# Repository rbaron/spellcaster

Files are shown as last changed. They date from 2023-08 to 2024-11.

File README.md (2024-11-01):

spellcaster Demo (https://youtu.be/c5Yf7bW8n6s)

spellcaster is a home automation magic wand. Click on the thumbnail above to watch it in action.

# How does it work?
An accelerometer and gyroscope are used to capture gestures ("spells"). Cast spells are then compared against previously stored ones. An action is triggered if there's a good match.

Different actions can be triggered. For example:
- A [BTHome.io](https://bthome.io) Bluetooth Low Energy (BLE) packet can be emitted and handled in [Home Assistant](https://www.home-assistant.io/).
- A Zigbee Cluster action, similarly handled in Home Assistant automations
- A [BLE-HID](https://novelbits.io/bluetooth-hid-devices-an-intro/) to simulate a key press on a computer, macro pad-style

In the "Software" section below, there are some firmware samples for each of these actions and more.

[This blog post](https://rbaron.net/blog/2023/10/27/spellcaster-a-home-automation-magic-wand.html) has a deeper dive into how everything works.

# Project status
It sort of works, but there are caveats. Reliability and usability need improvement -- it's easy to [hold it wrong](https://www.wired.com/2010/06/iphone-4-holding-it-wrong/). See "User interface" below. The code also needs the proverbial cleaning up.

Approach this project as a fun experiment. Expect fun and experimental support.

# Hardware
PCB

* [nRF52833](https://www.nordicsemi.com/Products/nRF52833) MCU
* [LSM6DSL](https://www.st.com/en/mems-and-sensors/lsm6dsl.html) IMU
* [Mini vibration motor](https://www.aliexpress.com/item/1005004653448729.html) for tactile feedback
* Powered by 2xAAA batteries

The [`kicad/`](./kicad/) directory contains the design and fabrication files. I used [JLCPCB](https://jlcpcb.com/) for manufacturing and assembly.

# User interface
## Casting spells
There is no on/off switch by design. To signal the *start of spell*, hold the wand horizontally flat. Once you start moving it, the gesture will start to be collected. To signal the *end of spell*, hold the wand horizontally flat again. Spells need to be between 500 milliseconds and 3 seconds in length.

## Record mode
To store a new spell in slot `S`, press the `A` button `S` times and cast a spell as described above. If everything goes well, the LED will flash five times and you will be switched to replay mode.

In this video you can see five different spells being recorded:

spellcaster recording spells (https://youtu.be/6D_qe5v8ILQ)

## Replay mode
This is the default mode in which spellcaster will live most of its life. Once a spell is cast, it will be compared to previously stored spells. If a good match is found, a vibration pattern is executed and an action will be triggered.

### On false positives
The matching algorithm is optimized for _something to happen_. There is a low threshold for matching spells, and often two or more will be sufficiently matched. This depends on how similar spells are, but the best matching spell will always be selected. The idea is that, when we intentionally cast a spell, the correct one will almost always be selected, instead of -- sometimes -- none. On the other hand, previously unseen spells may trigger a false positive.

This is done to mainly prevent the sorry sight of a full grown adult waving a wand in the air in front of friends and family at a dinner party and nothing happening. Don't ask. A better solution is to further tune the spell matching algorithm to be more robust against these cases, while retaining the precision when the casting is intentional. Another idea is to add an invisible capacitive touch sensor to the handle, which would also allow for much deeper sleep modes. Something to be improved.

## Deep sleep mode
If spellcaster is still for 10 seconds, it will enter the lowest power mode at around 65 uA. Most of which goes to the accelerometer, which lies semi-awake in a low power state waiting for movement. This can mostly likely be optimized further. Any movement will wake it up and into replay mode.

# Software
There are a few sample firmwares in the repository. They are all written with Nordic's [nRF Connect SDK](https://www.nordicsemi.com/Products/Development-software/nRF-Connect-SDK). Most samples are adapted from the SDK's examples.

| Directory | Description |
| --- | --- |
|[`code/sclib`](./code/sclib/)| Generic spellcaster library. Handles spell casting, storing and signal processing. Used by all other samples.|
|[`code/samples/ble-bthome`](./code/samples/ble-bthome/)|Matched spell `S` trigger a [BTHome.io](https://bthome.io) action that is equivalent to `S` button presses. This can then be used by [Home Assistant](https://homeassistant.io) automations. |
|[`code/samples/ble-hid`](./code/samples/ble-hid/)|spellcaster pairs with your computer via BLE. Matched spell `S` trigger a BLE-HID action that simulates a key press following the configurable [keymap](https://github.com/rbaron/spellcaster/blob/fc7ee0511366e4b62a08713fc59aa67fac9f286a/code/samples/ble-hid/src/main.c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).|
|[`code/samples/zigbee`](./code/samples/zigbee/)|Matched spells trigger Zigbee Cluster actions that can be used by [Home Assistant](https://homeassistant.io) automations. Unfortunately, the Zigbee specs don't define magic wand clusters, so the [spellcaster.py ZHA Quirk](https://github.com/rbaron/spellcaster/blob/main/code/samples/zigbee/zha/quirks/spellcaster.py) needs to be installed. With it, matched spell on slot `S` appears to be a "dim light" command with step `S`. Yikes! (And it's not even the worst hack around here). |
|[`code/samples/ble-dump`](./code/samples/ble-dump/)|Dumps raw accel & gyro spells over BLE. The [client.py](https://github.com/rbaron/spellcaster/blob/main/code/samples/ble-dump/client/client.py) connects to spellcaster and dumps the data to a file. This is how I collected the data for tuning the spell matching without cables getting in the way.|

## Building the samples
These are standard nRF Connect SDK projects with Zephyr RTOS, and the [official docs](https://nrfconnect.github.io/vscode-nrf-connect/index.html) apply. The [b-parasite project](https://github.com/rbaron/b-parasite) uses a similar setup with a generic library and different samples, and [the Wiki](https://github.com/rbaron/b-parasite/wiki/How-to-Build-the-Firmware-Samples) contains more details and alternatives.

## Flashing the samples
The samples are flashed with ARM's usual [SWD](https://developer.arm.com/documentation/ihi0031/a/The-Serial-Wire-Debug-Port--SW-DP-/Introduction-to-the-ARM-Serial-Wire-Debug--SWD--protocol). The [official docs](https://nrfconnect.github.io/vscode-nrf-connect/get_started/quick_debug.html) also apply. The only caveat is the custom, slim 6-testpoint SWD pins on the PCB. It also happens to the the exact same as described in the [b-parasite Wiki](https://github.com/rbaron/b-parasite/wiki/How-to-Flash-the-Firmware-Samples).

# Data analysis
The [`data/`](./data/) directory contains a bunch of Jupyter notebooks I used to tune the spell matching and some of the raw collected data.

# 3D printed case
fusion-case

The [`3dprint/`](./3dprint/) directory contains the STEP files for a 3D printed case. It's okay-ish, but could use some love. The 3D printed springs lose some tension after a while, and so do the clamps that hold both halves together. On the bright side, there's no glue nor screws involved. You can watch a video of the full assembly process [here](https://www.youtube.com/watch?v=kVlnX7w-8rc).

# License
## Hardware
spellcaster hardware © 2023 by rbaron is licensed under Creative Commons Attribution-ShareAlike 4.0 International (CC BY-SA 4.0). See [deed](https://creativecommons.org/licenses/by-sa/4.0/).

## Software
Software in this repository is licensed under the [MIT license](https://opensource.org/licenses/MIT). See [LICENSE_SOFTWARE](./LICENSE_SOFTWARE).

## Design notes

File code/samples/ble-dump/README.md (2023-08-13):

# check
A sample for checking the spellcaster board.

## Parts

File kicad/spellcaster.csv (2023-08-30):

Comment | Designator | Footprint | LCSC
4.7u | C1 | Capacitor_SMD:C_0402_1005Metric | C368809
100p | C11 | Capacitor_SMD:C_0402_1005Metric | C1546
47n | C13 | Capacitor_SMD:C_0402_1005Metric | C237221
12p | C2,C3,C4,C6 | Capacitor_SMD:C_0402_1005Metric | C1547
100n | C5,C10,C12,C14,C16 | Capacitor_SMD:C_0402_1005Metric | C1525
1p | C7 | Capacitor_SMD:C_0402_1005Metric | C1550
1.2p | C8 | Capacitor_SMD:C_0402_1005Metric | C1551
1u | C9,C15 | Capacitor_SMD:C_0402_1005Metric | C52923
LED | D1 | LED_SMD:LED_0603_1608Metric | C2286
1N4148W | D2 | Diode_SMD:D_SOD-323 | C2128
4.7nH | L1 | Inductor_SMD:L_0402_1005Metric | C963987
2.2nH | L2 | Inductor_SMD:L_0402_1005Metric | C108254
15nH | L3 | Inductor_SMD:L_0402_1005Metric | C27143
10uH | L4 | Inductor_SMD:L_1206_3216Metric | C1051
2N7002 | Q1 | Package_TO_SOT_SMD:SOT-23 | C8545
1k | R1 | Resistor_SMD:R_0402_1005Metric | C11702
10k | R2,R3,R4 | Resistor_SMD:R_0402_1005Metric | C60490
B3U-1000P | S1,S2 | Snapeda:SW_B3U-1000P | C231329
nRF52820-QDxx | U1 | Package_DFN_QFN:QFN-40-1EP_5x5mm_P0.4mm_EP3.6x3.6mm | C2895249
LSM6DSL | U2 | Package_LGA:LGA-14_3x2.5mm_P0.5mm_LayoutBorder3x4y | C126672
32k | Y1 | Crystal:Crystal_SMD_3215-2Pin_3.2x1.5mm | C32346
Crystal_GND24 | Y2 | Crystal:Crystal_SMD_2016-4Pin_2.0x1.6mm | C2149195

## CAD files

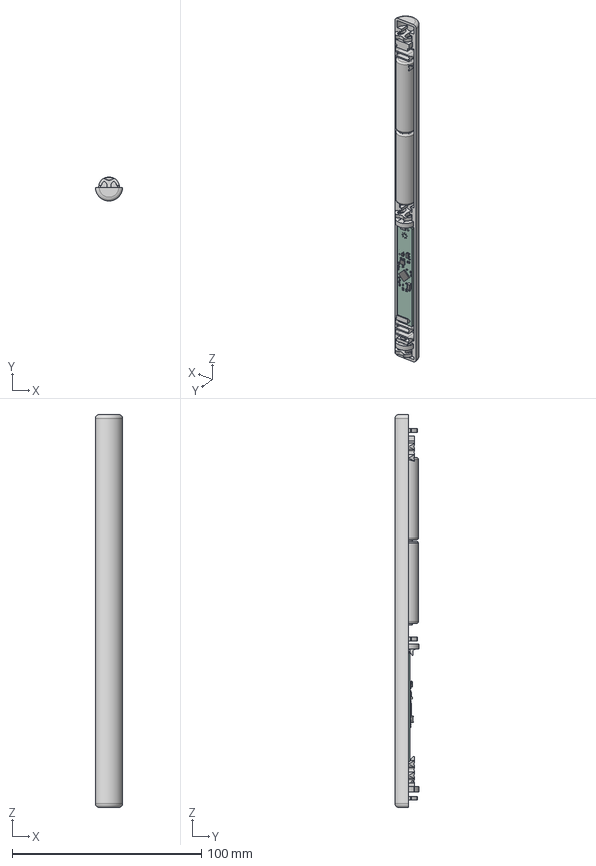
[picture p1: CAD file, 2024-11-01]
3dprint/spellcaster case.step
14.4 x 12.7 x 207.4 mm
PCB
batt1 x 2
vibration_motor
case
clip
spring
pcb_support

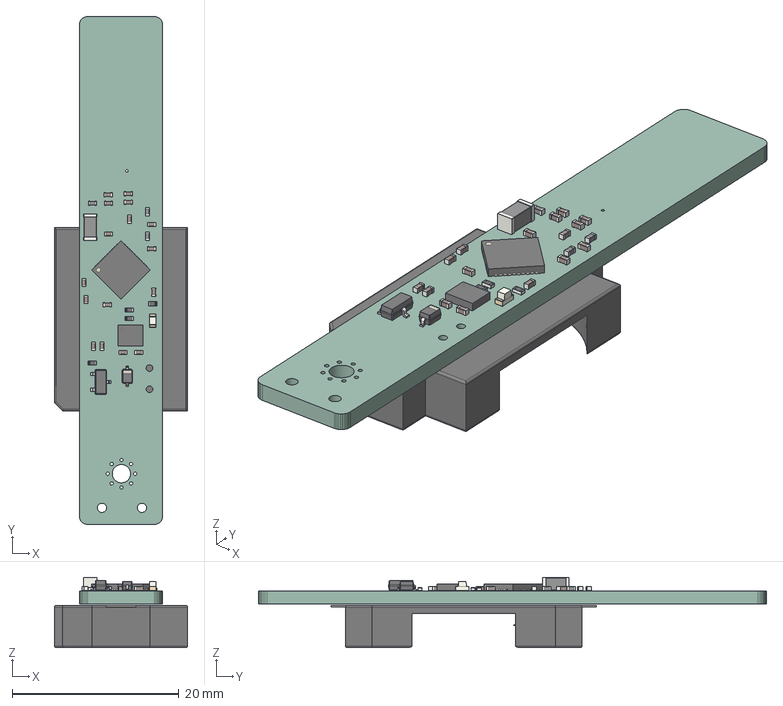
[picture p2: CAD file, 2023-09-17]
3dprint/spellcaster-pcb.step
16.0 x 61.0 x 8.46 mm
PCB

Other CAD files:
3dprint/spellcaster case.f3d

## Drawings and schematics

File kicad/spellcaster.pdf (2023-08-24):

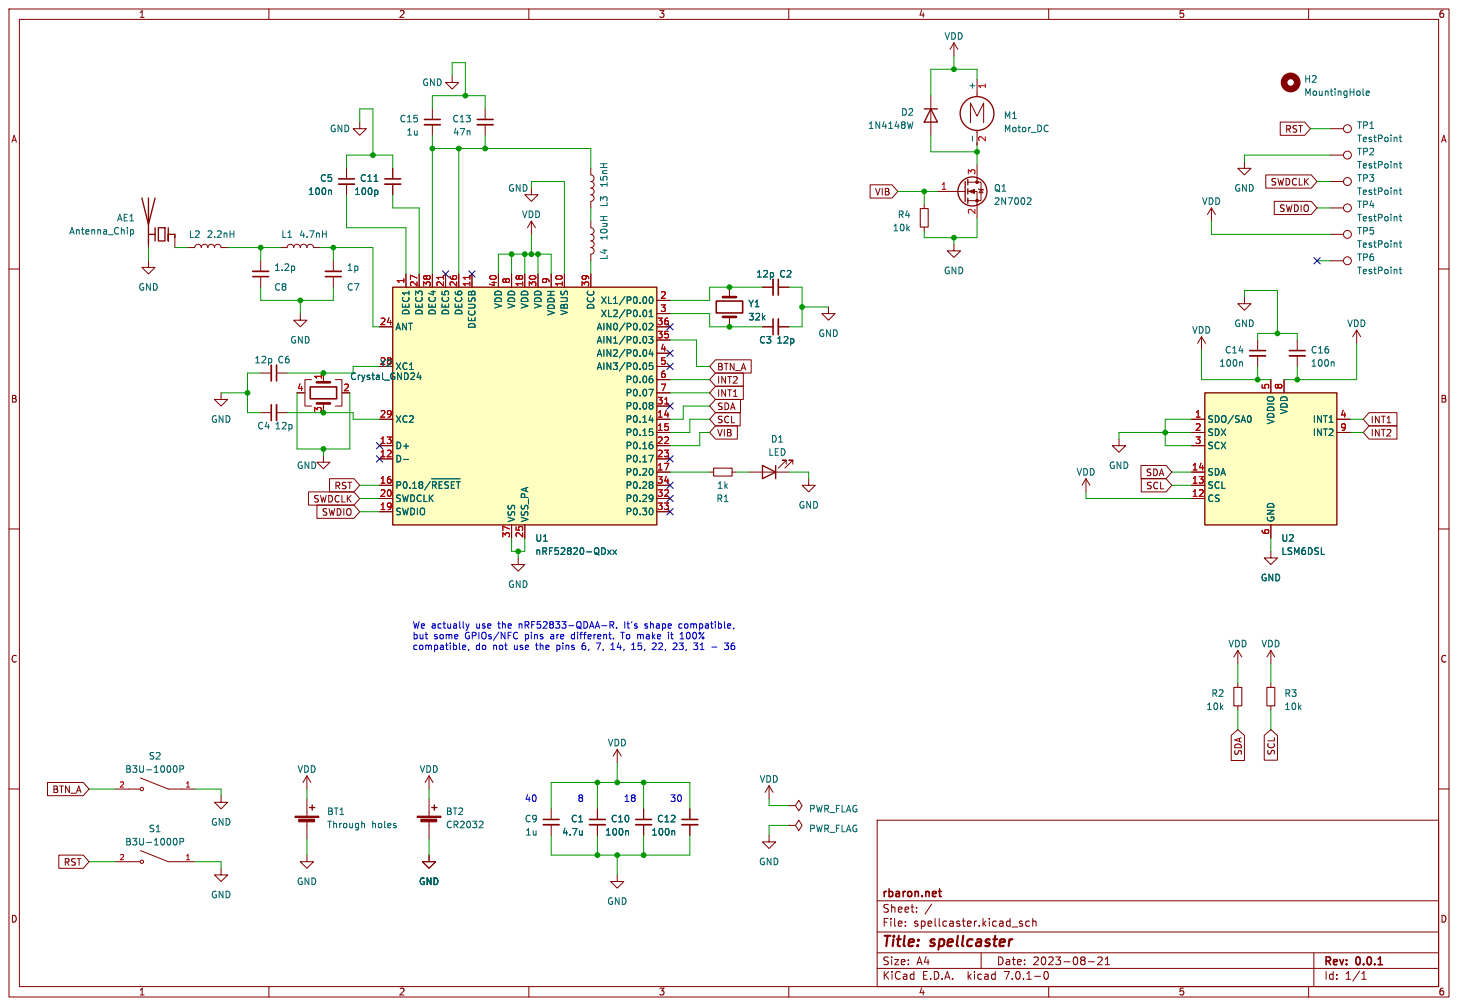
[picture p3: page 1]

1 VBUS 10 DECUSB 11 D- 12 D+ 13 P0.14 14 P0.15 15 P0.18/~{RESET} 16 P0.20 17 VDD 18 SWDIO 19 XL1/P0.00 2 SWDCLK 20 DEC5 21 P0.16 22 P0.17 23 ANT 24 VSS_PA 25 DEC6 26 DEC3 27 XC1 28 XC2 29 XL2/P0.01 VDD 3 30 P0.08 31 P0.29 32 P0.30 33 P0.28 34 AIN1/P0.03 35 AIN0/P0.02 36 VSS 37 DEC4 38 DCC 39 AIN2/P0.04 4 VDD 40 AIN3/P0.05 5 P0.06 6 P0.07 7 VDD

nRF52820-QDxx DEC1

Id: 1/1 Title: spellcaster File: spellcaster.kicad_sch Sheet: / rbaron.net VDD GND

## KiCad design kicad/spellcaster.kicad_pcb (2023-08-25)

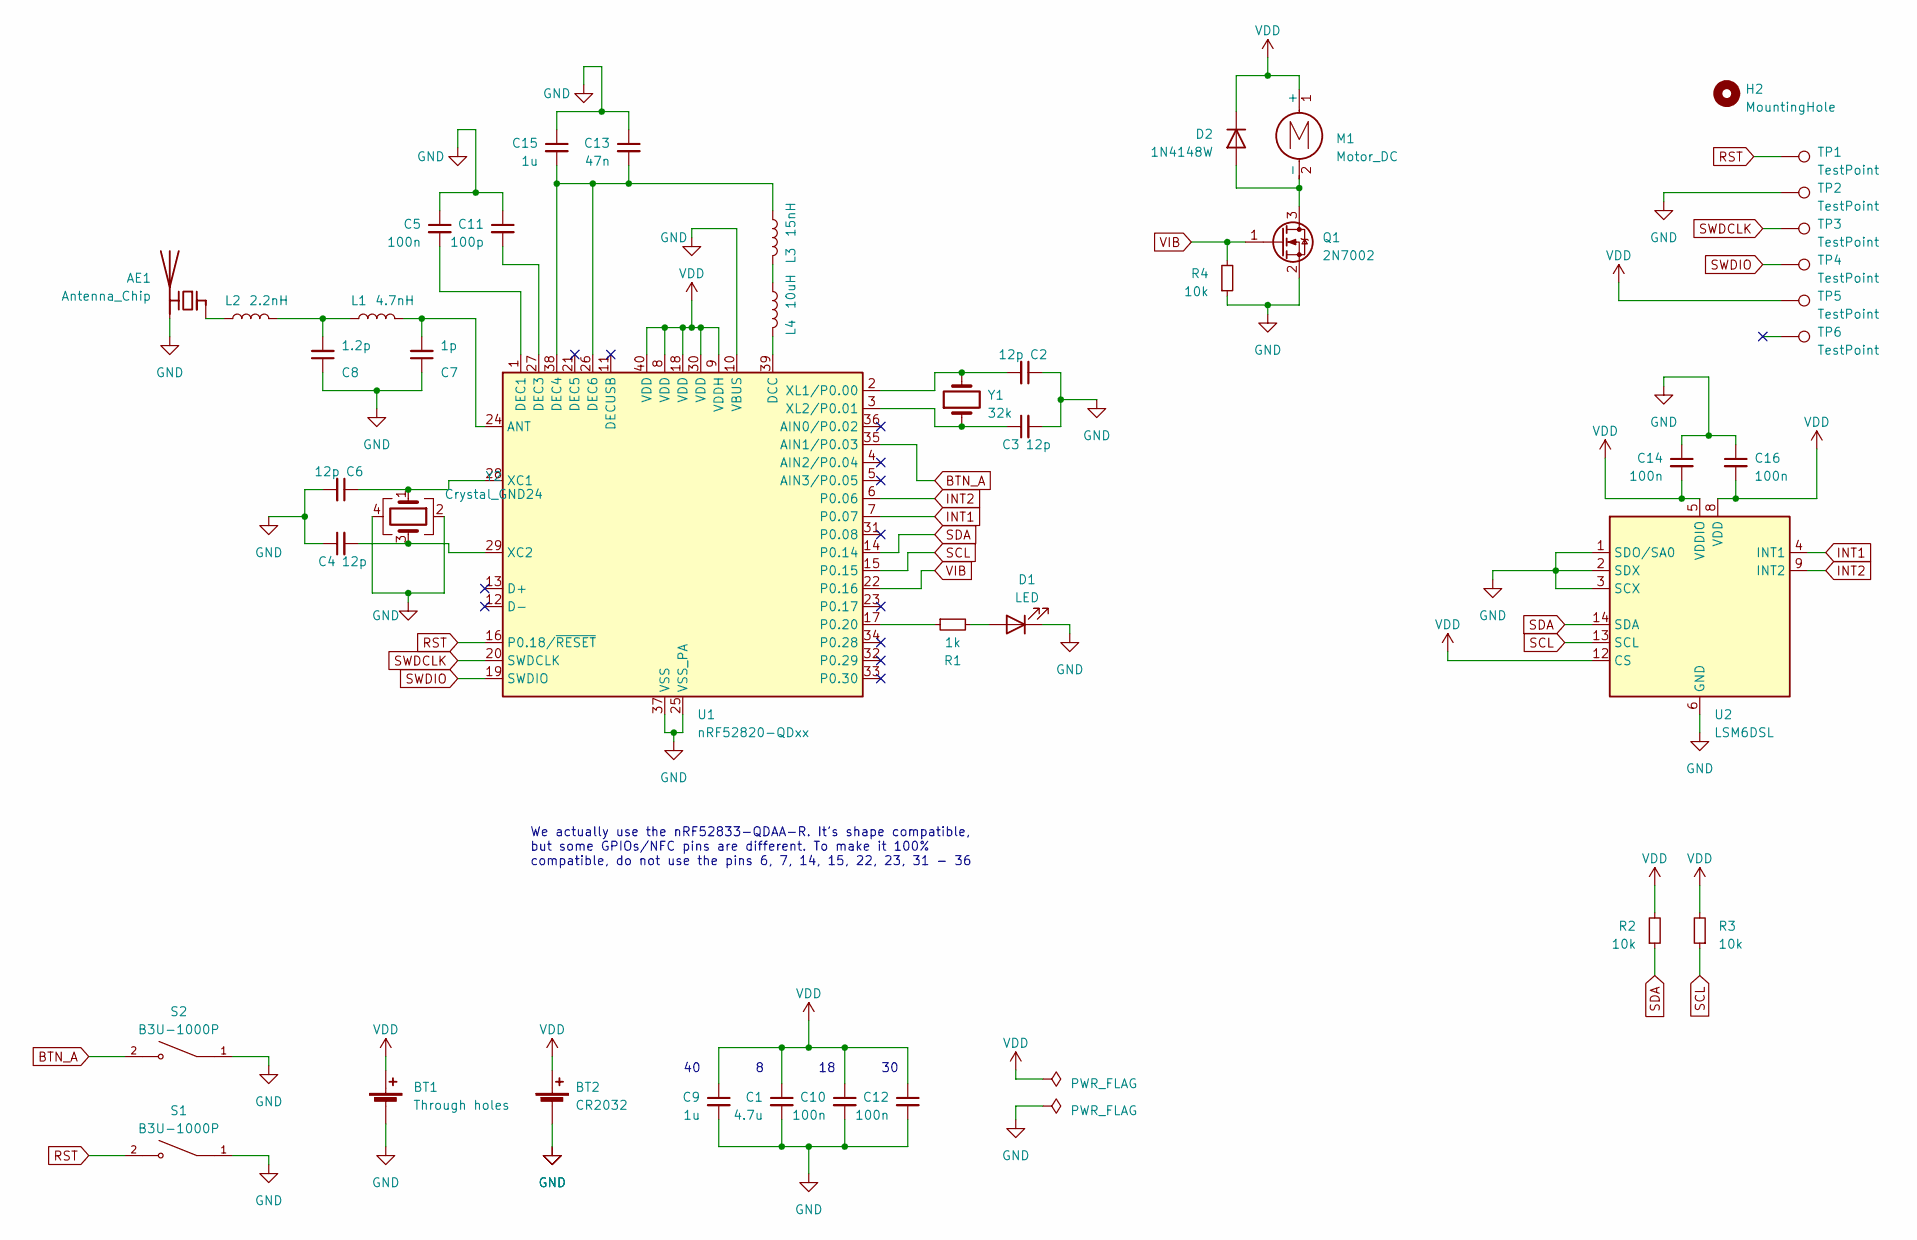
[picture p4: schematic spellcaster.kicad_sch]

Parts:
AE1: Antenna_Chip; Texas_SWRA117D_2.4GHz_Right
BT1: Through holes; SolderWire-0.5sqmm_1x02_P4.8mm_D0.9mm_OD2.3mm
BT2: CR2032; BatteryHolder_Keystone_1060_1x2032
C1: 4.7u; C_0402_1005Metric; LCSC C368809
C2, C3, C4, C6: 12p; C_0402_1005Metric; LCSC C1547
C5, C10, C12, C14, C16: 100n; C_0402_1005Metric; LCSC C1525
C7: 1p; C_0402_1005Metric; LCSC C1550
C8: 1.2p; C_0402_1005Metric; LCSC C1551
C9, C15: 1u; C_0402_1005Metric; LCSC C52923
C11: 100p; C_0402_1005Metric; LCSC C1546
C13: 47n; C_0402_1005Metric; LCSC C237221
D1: LED; LED_0603_1608Metric; LCSC C2286
D2: 1N4148W; D_SOD-323; LCSC C2128
H2: MountingHole; MountingHole_2.2mm_M2_Pad_Via
L1: 4.7nH; L_0402_1005Metric; LCSC C963987
L2: 2.2nH; L_0402_1005Metric; LCSC C108254
L3: 15nH; L_0402_1005Metric; LCSC C27143
L4: 10uH; L_1206_3216Metric; LCSC C1051
M1: Motor_DC; TestPoint_2Pads_Pitch2.54mm_Drill0.8mm
Q1: 2N7002; SOT-23; LCSC C8545
R1: 1k; R_0402_1005Metric; LCSC C11702
R2, R3, R4: 10k; R_0402_1005Metric; LCSC C60490
S1, S2: B3U-1000P; SW_B3U-1000P; LCSC C231329
TP1, TP2, TP3, TP4, TP5, TP6: TestPoint; TestPoint_Pad_D1.5mm
U1: nRF52820-QDxx; QFN-40-1EP_5x5mm_P0.4mm_EP3.6x3.6mm; LCSC C2895249
U2: LSM6DSL; LGA-14_3x2.5mm_P0.5mm_LayoutBorder3x4y; LCSC C126672
Y1: 32k; Crystal_SMD_3215-2Pin_3.2x1.5mm; LCSC C32346
Y2: Crystal_GND24; Crystal_SMD_2016-4Pin_2.0x1.6mm; LCSC C2149195

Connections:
BTN_A: S2.2, U1.35 (AIN1/P0.03)
GND: AE1.2 (PCB_Trace), BT1.2 (-), BT2.2 (-), C1.2, C2.1, C3.2, C4.1, C5.1, C6.2, C7.1, C8.1, C9.2, C10.2, C11.1, C12.2, C13.1, C14.1, C15.1, C16.1, D1.1 (K), Q1.2 (S), R4.1, S1.1, S2.1, TP2.1, U1.10 (VBUS), U1.25 (VSS_PA), U1.37 (VSS), U1.41 (VSS), U2.1 (SDO/SA0), U2.2 (SDX), U2.3 (SCX), U2.6 (GND), U2.7 (GND), Y2.2, Y2.4
INT1: U1.7 (P0.07), U2.4 (INT1)
INT2: U1.6 (P0.06), U2.9 (INT2)
unnamed: AE1.1 (FEED), L2.1
unnamed: C8.2, L1.1, L2.2
unnamed: D1.2 (A), R1.2
unnamed: D2.2 (A), M1.2 (-), Q1.3 (D)
unnamed: L3.1, L4.2
unnamed: C7.2, L1.2, U1.24 (ANT)
unnamed: L4.1, U1.39 (DCC)
unnamed: C5.2, U1.1 (DEC1)
unnamed: C11.2, U1.27 (DEC3)
unnamed: C13.2, C15.2, L3.2, U1.26 (DEC6), U1.38 (DEC4)
unnamed: R1.1, U1.17 (P0.20)
unnamed: C6.1, U1.28 (XC1), Y2.1
unnamed: C4.2, U1.29 (XC2), Y2.3
unnamed: C2.2, U1.2 (XL1/P0.00), Y1.2
unnamed: C3.1, U1.3 (XL2/P0.01), Y1.1
RST: S1.2, TP1.1, U1.16 (P0.18/~RESET)
SCL: R3.1, U1.15 (P0.15), U2.13 (SCL)
SDA: R2.1, U1.14 (P0.14), U2.14 (SDA)
SWDCLK: TP3.1, U1.20 (SWDCLK)
SWDIO: TP4.1, U1.19 (SWDIO)
VDD: BT1.1 (+), BT2.1 (+), C1.1, C9.1, C10.1, C12.1, C14.2, C16.2, D2.1 (K), M1.1 (+), R2.2, R3.2, TP5.1, U1.8 (VDD), U1.9 (VDDH), U1.18 (VDD), U1.30 (VDD), U1.40 (VDD), U2.5 (VDDIO), U2.8 (VDD), U2.12 (CS)
VIB: Q1.1 (G), R4.2, U1.22 (P0.16)

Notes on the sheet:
We actually use the nRF52833-QDAA-R. It's shape compatible, but some GPIOs/NFC pins are different. To make it 100% compatible, do not use the pins 6, 7, 14, 15, 22, 23, 31 - 36

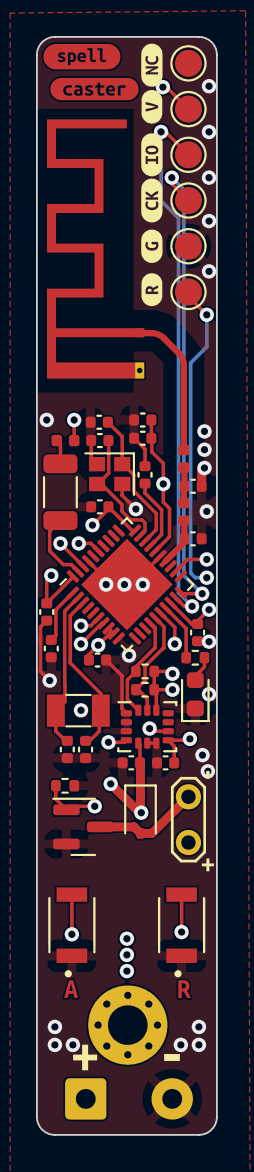
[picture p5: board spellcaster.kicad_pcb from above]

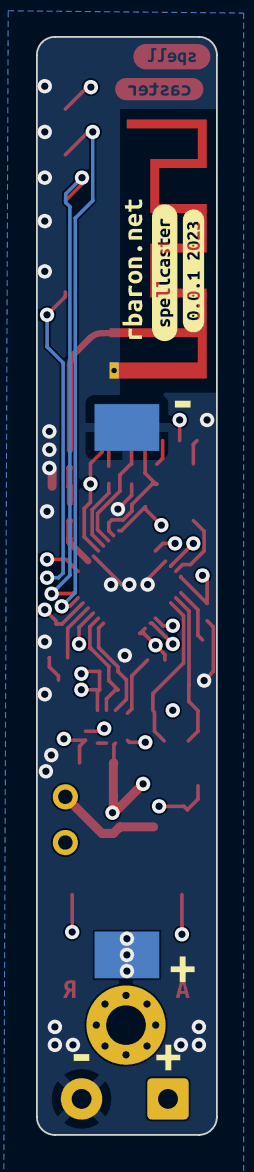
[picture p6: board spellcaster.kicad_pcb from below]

Board: 4 copper layers, 10.0 x 61.0 mm, 65 parts (8 on the bottom side), 26 nets.

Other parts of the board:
kibuzzard-64E66B38: G***; kibuzzard-64E66B38
kibuzzard-64E70B5B: G***; kibuzzard-64E70B5B
kibuzzard-64E70C98: G***; kibuzzard-64E70C98
kibuzzard-64E666A5: G***; kibuzzard-64E666A5
kibuzzard-64E666BF: G***; kibuzzard-64E666BF
kibuzzard-64E666C8: G***; kibuzzard-64E666C8
kibuzzard-64E666DB: G***; kibuzzard-64E666DB
kibuzzard-64E666EE: G***; kibuzzard-64E666EE
kibuzzard-64E668FF, kibuzzard-64E668FF#2, kibuzzard-64E668FF#3: G***; kibuzzard-64E668FF
kibuzzard-64E704EF: G***; kibuzzard-64E704EF
kibuzzard-64E705F6: G***; kibuzzard-64E705F6
kibuzzard-64E7057C: G***; kibuzzard-64E7057C
kibuzzard-64E7063C: G***; kibuzzard-64E7063C
kibuzzard-64E66706: G***; kibuzzard-64E66706
kibuzzard-64E66855: G***; kibuzzard-64E66855
kibuzzard-64E66915, kibuzzard-64E66915#2: G***; kibuzzard-64E66915
kibuzzard-64E70501: G***; kibuzzard-64E70501
kibuzzard-64E70567: G***; kibuzzard-64E70567

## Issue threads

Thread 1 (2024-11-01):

3D Printed Case files not as per videos and pictures?

comm, 2024-11-01:
I note the f3d file does not show the same design as the pictures and video on the readme - can you please upload the latest version?

Thank you.

rbaron, 2024-11-01:
Indeed I made a lot of changes after exporting those files. I re-exported them now in the main branch.

If you're really building the whole project, make sure to read the [project status](https://github.com/rbaron/spellcaster?tab=readme-ov-file#project-status). While I'm very excited to see someone building it, keep in mind that this is very experimental and there are many annoying quirks and very rough edges everywhere that can be frustrating. I myself haven't had time to work on it over the past year, so I can only offer limited support.

With that out of the way, please keep me posted on your progress. I'd love to see someone else have some fun with it.

comm, 2024-11-02:
Superb, thank you. I appreciate the words of caution. Your knowledge to get to this point is well beyond my skill, but I'm sure I'll trouble shoot as best I can before coming your way, but will definitely let you know how it goes.

Closed 2024-11-02.

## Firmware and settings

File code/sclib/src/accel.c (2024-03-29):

#include "sclib/accel.h"

#include <zephyr/drivers/gpio.h>
#include <zephyr/drivers/i2c.h>
#include <zephyr/kernel.h>
#include <zephyr/logging/log.h>

#include "sclib/led.h"
#include "sclib/lsm6dsl_regs.h"
#include "sclib/macros.h"
#include "sclib/mpu6050_regs.h"

#define PARSES16(buf, i) (((int16_t)buf[i] << 8) | (int16_t)buf[i + 1])
#define PARSEU16(buf, i) (((uint16_t)buf[i] << 8) | (uint16_t)buf[i + 1])

#define PARSES16BE(buf, i) (((int16_t)buf[i + 1] << 8) | (int16_t)buf[i])

// LOG_MODULE_REGISTER(accel, CONFIG_SCLIB_LOG_LEVEL);
LOG_MODULE_REGISTER(accel, LOG_LEVEL_DBG);

#if DT_NODE_EXISTS(DT_NODELABEL(mpu))

static const struct i2c_dt_spec mpu = I2C_DT_SPEC_GET(DT_NODELABEL(mpu));

static const int16_t calibration_offsets[6] = {-1708, 755, 1014, 114, 32, -3};

static int write_reg_16(uint8_t reg, int16_t val) {
  uint8_t buf[3];
  buf[0] = reg;
  buf[1] = val >> 8;
  buf[2] = val & 0xff;
  return i2c_write_dt(&mpu, buf, sizeof(buf));
}

int sc_accel_init(void) {
  RET_IF_ERR_MSG(!device_is_ready(mpu.bus), "MPU6050 is not ready");

  // Reset.
  RET_IF_ERR(i2c_reg_write_byte_dt(&mpu, MPU6050_PWR_MGMT_1, 0x80));

  // Upload offsets. Not sure this is actually helpful.
  RET_IF_ERR(write_reg_16(MPU6050_XA_OFFS_H, calibration_offsets[0]));
  RET_IF_ERR(write_reg_16(MPU6050_YA_OFFS_H, calibration_offsets[1]));
  RET_IF_ERR(write_reg_16(MPU6050_ZA_OFFS_H, calibration_offsets[2]));
  RET_IF_ERR(write_reg_16(MPU6050_XG_OFFS_H, calibration_offsets[3]));
  RET_IF_ERR(write_reg_16(MPU6050_YG_OFFS_H, calibration_offsets[4]));
  RET_IF_ERR(write_reg_16(MPU6050_ZG_OFFS_H, calibration_offsets[5]));

  // Set clock source x gyro.
  RET_IF_ERR(i2c_reg_write_byte_dt(&mpu, MPU6050_PWR_MGMT_1, 0x01));
  // Set gyro range to +/- 500 deg/s.
  RET_IF_ERR(i2c_reg_write_byte_dt(&mpu, MPU6050_GYRO_CONFIG, 0x01));
  // Enable accel and gyro in fifo.
  RET_IF_ERR(i2c_reg_write_byte_dt(&mpu, MPU6050_FIFO_EN, 0x78));
  // Set fifo rate to 50 Hz.
  RET_IF_ERR(i2c_reg_write_byte_dt(&mpu, MPU6050_SMPLRT_DIV, 159));
  // Enable and reset fifo.
  RET_IF_ERR(i2c_reg_write_byte_dt(&mpu, MPU6050_USER_CTRL, 0x44));
  return 0;
}

int sc_accel_read(struct sc_accel_entry *entry) {
  // Read fifo count.
  uint8_t write_buf[1] = {MPU6050_FIFO_COUNTH};
  uint8_t read_buf[2];
  RET_IF_ERR(i2c_write_read_dt(&mpu, write_buf, 1, read_buf, 2));
  uint16_t fifo_count = PARSEU16(read_buf, 0);

  // Read fifo.
  if (fifo_count <= 0) {
    return -1;
  }

  uint8_t fifo_buf[sizeof(int16_t) * 6];
  write_buf[0] = MPU6050_FIFO_R_W;
  RET_IF_ERR(i2c_write_read_dt(&mpu, write_buf, 1, fifo_buf, sizeof(fifo_buf)));

  entry->ax = PARSES16(fifo_buf, 0);
  entry->ay = PARSES16(fifo_buf, 2);
  entry->az = PARSES16(fifo_buf, 4);
  entry->gx = PARSES16(fifo_buf, 6);
  entry->gy = PARSES16(fifo_buf, 8);
  entry->gz = PARSES16(fifo_buf, 10);

  return 0;
}

#elif DT_NODE_EXISTS(DT_NODELABEL(lsm6dsl))

static const struct gpio_dt_spec int_1_dt =
    GPIO_DT_SPEC_GET(DT_NODELABEL(int_1), gpios);

struct gpio_callback interrupt_cb_data;

static const struct i2c_dt_spec mpu = I2C_DT_SPEC_GET(DT_NODELABEL(lsm6dsl));

// User supplied callback.
static sc_accel_evt_handler_t user_callback = NULL;

static void isr_work_handler(struct k_work *work) {
  // Read wake up source.
  uint8_t write_buf[1] = {LSM6DSL_WAKE_UP_SRC};
  uint8_t read_buf[1];
  if (i2c_write_read_dt(&mpu, write_buf, sizeof(write_buf), read_buf,
                        sizeof(read_buf))) {
    LOG_ERR("Error reading wake up source");
    return;
  }

  LOG_DBG("WAKE_UP_SRC: 0x%02x", read_buf[0]);

  if (!user_callback) {
    return;
  }

  if (read_buf[0] & (0b1 << 4)) {
    user_callback(SC_ACCEL_SLEEP_EVT);
  } else if (read_buf[0] & 0x0f) {
    user_callback(SC_ACCEL_WAKEUP_EVT);
  }
}

// Define work.
K_WORK_DEFINE(isr_work, isr_work_handler);

static void interrupt_callback(const struct device *dev,
                               struct gpio_callback *cb, uint32_t pins) {
  // Create work.
  k_work_submit(&isr_work);
}

int sc_accel_init(void) {
  RET_IF_ERR_MSG(!device_is_ready(mpu.bus), "LSM6DSL is not ready");

  uint8_t write_buf[1] = {LSM6DSL_WHO_AM_I};
  uint8_t read_buf[1];
  RET_IF_ERR(i2c_write_read_dt(&mpu, write_buf, sizeof(write_buf), read_buf,
                               sizeof(read_buf)));
  // LOG_ERR("WHO_AM_I: 0x%02x", read_buf[0]);

  // To reset FIFO, set FIFO_MODE to BYPASS and then back to FIFO.
  // RET_IF_ERR(i2c_reg_write_byte_dt(&mpu, LSM6DSL_FIFO_CTRL5, 0x00));
  // RET_IF_ERR(i2c_reg_write_byte_dt(&mpu, LSM6DSL_FIFO_CTRL5, 0x01));

  // Set accel to 52 Hz and 4g.
  RET_IF_ERR(i2c_reg_write_byte_dt(&mpu, LSM6DSL_CTRL1_XL, 0x30 | 0b1000));

  // Set gyro to 52 Hz and 500 dps.
  RET_IF_ERR(i2c_reg_write_byte_dt(&mpu, LSM6DSL_CTRL2_G, 0x30 | 0b1000));

  // Set FIFO to 52 Hz & FIFO mode.
  // RET_IF_ERR(
  //     i2c_reg_write_byte_dt(&mpu, LSM6DSL_FIFO_CTRL5, (0b0011 << 3) |
  //     0b001));
  RET_IF_ERR(sc_accel_reset_fifo());

  // Enable accel and gyro in fifo.
  RET_IF_ERR(i2c_reg_write_byte_dt(&mpu, LSM6DSL_FIFO_CTRL3, (0b1 << 3) | 0b1));

  // Enable activity interrupts.
  // INTERRUPTS_ENABLE & INACT_EN.
  RET_IF_ERR(i2c_reg_write_byte_dt(&mpu, LSM6DSL_TAP_CFG, 0xe0));
  // Set duration to wake up to 3 * ODR_timer (~ 60 ms) and duration to go to
  // sleep to 512/ODR (~10 s).
  RET_IF_ERR(
      i2c_reg_write_byte_dt(&mpu, LSM6DSL_WAKE_UP_DUR, (0b11 << 5) | 0x01));
  RET_IF_ERR(i2c_reg_write_byte_dt(&mpu, LSM6DSL_WAKE_UP_THS, 0x01));
  // Set duration to go to sleep as 512/ODR ~= 10 seconds.

  // Enable wake up interrupt on INT1.
  RET_IF_ERR(i2c_reg_write_byte_dt(&mpu, LSM6DSL_MD1_CFG, 0x80));

  // Init interrupt pins.
  RET_IF_ERR(!device_is_ready(int_1_dt.port));
  RET_IF_ERR(gpio_pin_configure_dt(&int_1_dt, GPIO_INPUT));
  RET_IF_ERR(
      gpio_pin_interrupt_configure_dt(&int_1_dt, GPIO_INT_EDGE_TO_ACTIVE));

  // Initialize GPIO callback.
  gpio_init_callback(&interrupt_cb_data, interrupt_callback, BIT(int_1_dt.pin));
  RET_IF_ERR(gpio_add_callback(int_1_dt.port, &interrupt_cb_data));

  LOG_DBG("LSM6DSL init done");

  return 0;
}

int sc_accel_sleep(void) {
  // Software reset.
  // RET_IF_ERR(i2c_reg_write_byte_dt(&mpu, LSM6DSL_CTRL3_C, 0x01));
  // k_msleep(100);

  // Disable fifo.
  // RET_IF_ERR(i2c_reg_write_byte_dt(&mpu, LSM6DSL_FIFO_CTRL3, 0x00));

  return 0;
}

int sc_accel_set_evt_handler(sc_accel_evt_handler_t handler) {
  user_callback = handler;
  return 0;
}

static inline int16_t read_fifo_entry() {
  uint8_t write_buf[1] = {LSM6DSL_FIFO_DATA_OUT_L};
  uint8_t read_buf[2];
  RET_IF_ERR(i2c_write_read_dt(&mpu, write_buf, 1, read_buf, sizeof(read_buf)));
  return PARSES16BE(read_buf, 0);
}
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

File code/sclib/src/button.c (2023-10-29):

#include "sclib/button.h"

#include <zephyr/drivers/gpio.h>
#include <zephyr/kernel.h>
#include <zephyr/logging/log.h>

#include "sclib/macros.h"

#define SC_DEBOUNCING_INTERVAL K_MSEC(5)
#define SC_LONG_PRESS_DURATION K_MSEC(250)
#define SC_DOUBLE_PRESS_CB_INTERVAL K_MSEC(400)

LOG_MODULE_REGISTER(button, CONFIG_SCLIB_LOG_LEVEL);

typedef struct {
  sc_button_t button;
  bool handled_long_press;
  uint8_t n_presses;
  struct gpio_dt_spec button_dt;
  struct gpio_callback cb_data;
  // Used for debouncing.
  struct k_work_delayable debouncing_delayable;
  struct k_work_delayable double_press_delayable;
  struct k_work_delayable long_press_delayable;
} button_cfg_t;

static button_cfg_t button_cfgs[] = {
    {.button = SC_BUTTON_A,
     .handled_long_press = false,
     .n_presses = 0,
     .button_dt = GPIO_DT_SPEC_GET(DT_NODELABEL(button_a), gpios)},
};

static sc_button_callback_t user_callback = NULL;

static void maybe_call_user_callback(sc_button_t button,
                                     sc_button_event_t event) {
  LOG_DBG("Calling user callback for button %d, event %d", (int)button,
          (int)event);
  if (user_callback != NULL) {
    user_callback(button, event);
  } else {
    LOG_WRN("No user callback registered for button %d", button);
  }
}
static void double_press_cb(struct k_work *work) {
  struct k_work_delayable *delayable =
      CONTAINER_OF(work, struct k_work_delayable, work);
  button_cfg_t *cfg =
      CONTAINER_OF(delayable, button_cfg_t, double_press_delayable);
  uint8_t n_presses = cfg->n_presses;
  cfg->n_presses = 0;

  if (n_presses == 1) {
    LOG_DBG("Button %d single press event", cfg->button);
    maybe_call_user_callback(cfg->button, SC_BUTTON_EVENT_SHORT_PRESS);
  } else if (n_presses == 2) {
    LOG_DBG("Button %d double press event", cfg->button);
    maybe_call_user_callback(cfg->button, SC_BUTTON_EVENT_DOUBLE_PRESS);
  } else if (n_presses == 3) {
    LOG_DBG("Button %d triple press event", cfg->button);
    maybe_call_user_callback(cfg->button, SC_BUTTON_EVENT_TRIPLE_PRESS);
  } else if (n_presses == 4) {
    LOG_DBG("Button %d quadruple press event", cfg->button);
    maybe_call_user_callback(cfg->button, SC_BUTTON_EVENT_QUADRUPLE_PRESS);
  } else if (n_presses == 5) {
    LOG_DBG("Button %d quintuple press event", cfg->button);
    maybe_call_user_callback(cfg->button, SC_BUTTON_EVENT_QUINTUPLE_PRESS);
  } else if (n_presses == 6) {
    LOG_DBG("Button %d sextuple press event", cfg->button);
    maybe_call_user_callback(cfg->button, SC_BUTTON_EVENT_SEXTUPLE_PRESS);
  } else {
    LOG_WRN("Button %d unexpected number of presses: %d", cfg->button,
            n_presses);
  }
}

static void long_press_cb(struct k_work *work) {
  struct k_work_delayable *delayable =
      CONTAINER_OF(work, struct k_work_delayable, work);
  button_cfg_t *cfg =
      CONTAINER_OF(delayable, button_cfg_t, long_press_delayable);
  cfg->handled_long_press = true;
  maybe_call_user_callback(cfg->button, SC_BUTTON_EVENT_LONG_PRESS);
}

static void button_pressed_cb(struct k_work *work) {
  struct k_work_delayable *delayable =
      CONTAINER_OF(work, struct k_work_delayable, work);
  button_cfg_t *cfg =
      CONTAINER_OF(delayable, button_cfg_t, debouncing_delayable);
  int button_active = sc_button_poll(cfg->button);
  LOG_DBG("Button %d pressed, handled_long_press %d, n_presses %d, active %d",
          cfg->button, cfg->handled_long_press, cfg->n_presses, button_active);

  if (button_active) {
    // First press, schedule long press callback.
    if (cfg->n_presses == 0) {
      LOG_DBG("Scheduling long press callback");
      k_work_reschedule(&cfg->long_press_delayable, SC_LONG_PRESS_DURATION);
    }
    // Button inactive.
  } else {
    // Sync?
    // Cancel if work has not ran yet.
    LOG_DBG("Canceling long press callback");
    k_work_cancel_delayable(&cfg->long_press_delayable);
    // We only consider short button presses if it didn't run the long press
    // handler.
    if (!cfg->handled_long_press) {
      LOG_DBG("Button %d scheduling double_press_delayable", cfg->button);
      cfg->n_presses += 1;
      k_work_reschedule(&cfg->double_press_delayable,
                        SC_DOUBLE_PRESS_CB_INTERVAL);
    } else {
      LOG_DBG("Button %d handled long press, ignoring short press",
              cfg->button);
      cfg->handled_long_press = false;
    }
  }
}

static void button_pressed_isr(const struct device *dev,
                               struct gpio_callback *cb, uint32_t pins) {
  button_cfg_t *cfg = CONTAINER_OF(cb, button_cfg_t, cb_data);
  k_work_reschedule(&cfg->debouncing_delayable, SC_DEBOUNCING_INTERVAL);
}

int sc_button_init() {
  for (int i = 0; i < ARRAY_SIZE(button_cfgs); i++) {
    button_cfg_t *cfg = &button_cfgs[i];
    RET_IF_ERR(!device_is_ready(cfg->button_dt.port));
    RET_IF_ERR(gpio_pin_configure_dt(&cfg->button_dt, GPIO_INPUT));
    k_work_init_delayable(&cfg->debouncing_delayable, button_pressed_cb);
    k_work_init_delayable(&cfg->double_press_delayable, double_press_cb);
    k_work_init_delayable(&cfg->long_press_delayable, long_press_cb);
    // EDGE interrupts seem to consume more power than LEVEL ones.
    // For GPIO_INT_EDGE_BOTH: 16 uA idle.
    // For GPIO_INT_LEVEL_ACTIVE: 3 uA idle.
    // Related issue:
    // https://github.com/zephyrproject-rtos/zephyr/issues/28499
    // Apparently sense-edge-mask brings the power consumption down to
    // 3 uA for EDGE interrupts too.
    RET_IF_ERR(
        gpio_pin_interrupt_configure_dt(&cfg->button_dt, GPIO_INT_EDGE_BOTH));
    gpio_init_callback(&cfg->cb_data, button_pressed_isr,
                       BIT(cfg->button_dt.pin));
    RET_IF_ERR(gpio_add_callback(cfg->button_dt.port, &cfg->cb_data));
  }
  return 0;
}

int sc_button_register_callback(sc_button_callback_t callback) {
  user_callback = callback;
  return 0;
}

int sc_button_poll(sc_button_t sc_button) {
  button_cfg_t *cfg = &button_cfgs[sc_button];
  return gpio_pin_get_dt(&cfg->button_dt);
}

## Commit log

2023-08-13 Initial commit
    Sample `check` seems to compile
2023-08-14 Ported some Arduino prototype code
2023-08-15 Ported obw/ble-bthome
    Still needs lots of memory opt. Currently CONFIG_ASSERT makes it almost
    run out of RAM
2023-08-15 ble-bthome + caster kinda works for two slots
    But RAM is close to full, had to limit signal storage to 2s
2023-08-21 Copied and renamed obw's kicad proj here
    [spellcaster.kicad_pcb, spellcaster.kicad_sch]
2023-08-23 Initial routing
    [spellcaster.kicad_pcb, spellcaster.kicad_sch]
2023-08-23 Smaller, graphics
    [spellcaster.kicad_pcb]
2023-08-23 Round edges
    [spellcaster.kicad_pcb]
2023-08-23 Silkscreen + stitching
    [spellcaster.kicad_pcb, spellcaster.kicad_sch]
2023-08-24 Add vibration motor
    [spellcaster.kicad_pcb, spellcaster.kicad_sch]
2023-08-24 Fixes vibration motor routing
    [spellcaster.kicad_pcb]
2023-08-24 Add optional CR2032 holder
    [spellcaster.kicad_pcb, spellcaster.kicad_sch]
2023-08-24 Fixed missing accel vcc connection
    [spellcaster.kicad_pcb, spellcaster.kicad_sch]
2023-08-24 DRC happy
    [spellcaster.kicad_pcb]
2023-08-24 Plotted and ordered
    [spellcaster-B_Cu.gbl, spellcaster-B_Mask.gbs, spellcaster-B_Paste.gbp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]
2023-08-25 Fixed wrong package for D1
    [spellcaster.kicad_pcb, spellcaster.kicad_sch]
2023-08-30 Updated D1 footprint
    ... After feedback from JLC engineers. This is the actual produced
    version 0.0.1
    [spellcaster-B_Cu.gbl, spellcaster-B_Mask.gbs, spellcaster-B_Paste.gbp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]
2023-09-15 [accel] Reading gyro & accel works -- hacky
2023-09-16 Quick hack for dumping signals to RTT
    [circles.csv, z.csv]
2023-09-17 New data
    [circles.csv, swipe.csv, z.csv]
2023-09-17 Added pcb STEP
    [spellcaster-pcb.step]
2023-10-07 V0 case (white PETG)
    [spellcaster case v38.f3d]
2023-10-08 Updated case
    Not ideal, but works with some massaging
    [spellcaster case v38.f3d, spellcaster case v45.f3d]
2023-10-08 PWM for vibration & some improvements to state machine
    [vibration.c]
2023-10-09 [ble-dump] Initial service & client works, now needs real data
    [oi.csv]
2023-10-09 Simpe ble-dump dumps & jupyter notebook
    [L.csv, circle.csv, oi.csv]
2023-10-10 [ble-bthome] Kinda works ok now!
    [L.csv, X.csv, circle.csv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]
2023-10-13 Rotation invariance works... In theory (notebook)
    [L-rot-inv.csv, circle-rot-inv.csv]
2023-10-14 Rotation invariance works!
    [X-rot-inv.csv]
2023-10-17 Vib async, lower horiz timer to 250 ms (max samples = 2.4s still)
2023-10-25 Port one-bit-wonder's zigbee sample
2023-10-25 ble-hid works, but I'm gonna have to undo a lot of hacks
    Main issue took a while to figure out: CONFIG_SETTINGS (&
    CONFIG_BT_SETTINGS) also use the `storage` partition. Since we use it at
    the same time for LittleFS, shit goes down and it's really hard to
    debug. Just a bunch of gibberish in logs, which I thought it was a stack
    overflow and chased that wrong thread for hours...
    [main.c]
2023-10-29 6 button press, max signals lengths diff
    [down_I-rot-inv.csv]
2023-10-29 Add uptick dump
    [uptick-rot-inv.csv]
2024-03-29 Fixed (?) state machine
    [accel.c]
2024-05-06 Update case link in README.md
2024-11-01 Add latest 3dprint files
    [spellcaster case v45.f3d, spellcaster case.f3d, spellcaster case.step]
